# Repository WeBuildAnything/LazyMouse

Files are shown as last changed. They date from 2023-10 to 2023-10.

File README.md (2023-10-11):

# LazyMouse
Based on Arduino library [ESP32 BLE Combo Keyboard & Mouse](https://github.com/blackketter/ESP32-BLE-Combo.git) library by blackketter, which is a fork of T-vK Library.

The IMU sensor uses the [MPU6050 library by Electronic Cats](https://github.com/ElectronicCats/mpu6050.git).

Download and install these libraies before running the code.
# Features
1) Air Mouse with Left and Right Clicks 
2) Vertical and Horizontal Scrolling with Middle Click
3) Volume Control
4) Mute Key
5) Media Control (Play/Pause, Next, Previous)
6) Battery Voltage Sensing and Update every 15 mins

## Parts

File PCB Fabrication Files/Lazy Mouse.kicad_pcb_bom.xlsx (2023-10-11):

designator | quantity | manufacturer | Mfg Part # | value | pack | mount_type
BACK1, L_CLICK1 | 2 | OMRON | D3SH-A0R1 | D3SH-A0R1 | D3SH-_0R1 | smt
C1 | 1 | MURATA | GRM188R72A103KA01J | 10nF | C_0603_1608Metric | smt
C10, C11, C12, C13, C14, C15, C16, C17, C18, C19, C2, C20, C21, C3, C4, C9 | 16 | MURATA | GRM188R72A104KA35J | 0.1uF | C_0603_1608Metric | smt
C5 | 1 | MURATA | GRM1885C2A222JA01D | 2.2nF | C_0603_1608Metric | smt
C6, C8 | 2 | MURATA | GRM188R61A106ME69J | 10uF | C_0603_1608Metric | smt
C7 | 1 | MURATA | GRM188R61C475KE11D | 4.7uF | C_0603_1608Metric | smt
CON1 | 1 |  |  | PinHeader_1x03_P1.00mm_Vertical | PinHeader_1x03_P1.00mm_Vertical | tht
FORWARD1, R_CLICK1 | 2 | OMROM | D3SH-A0L1 | D3SH-A0L1 | D3SH-_0L1 | smt
IC1 | 1 | MICROCHIP | MCP73833 | MCP73833 | SOP50P490X110-10N | smt
IC2 | 1 | TEXAS INSTRUMENTS | LM3671MF | LM3671MF | SOT95P280X145-5N | smt
J1 | 1 | GCT | USB4105-GF-A | USB_C_Receptacle_USB2.0 | USB_C_Receptacle_GCT_USB4105-xx-A_16P_TopMnt_Horizontal | smt
J2 | 1 | MOLEX | 53261-0271 | 53261-0271 | 532610271 | smt
L1 | 1 | TAIYO YUDEN | NRH2412T2R2MNGH | 2.2uH | NRH2412T2R2MNGH | smt
LED1 | 1 | WURTH ELECTRONICS | 150353M153300 | 150353M153300 | 150353M153300 | smt
R1, R15, R2, R3, R4, R5, R6 | 7 | PANASONIC | ERJ-S03J103V | 10k | R_0603_1608Metric | smt
R10, R11, R14, R7, R8 | 5 | PANASONIC | ERJ-P03J122V | 1.2k | R_0603_1608Metric | smt
R12, R13 | 2 | PANASONIC | ERJ-S03J512V | 5.1k | R_0603_1608Metric | smt
R16 | 1 | PANASONIC | ERJ-U03J104V | 100k | R_0603_1608Metric | smt
R9 | 1 | BOURNS | CR0603-FX-54R9ELF | 55 | R_0603_1608Metric | smt
S1 | 1 | E-SWITCH | JS1400BFQ | JS1400BFQ | JS1400BFQ | tht
S2, S3, S4 | 3 | PANASONIC | EVQ-P0N02B | EVQ-P0N02B | EVQP0N02B | smt
S5 | 1 | C&K SWITCHES | PCM12SMTR | PCM12SMTR | PCM12SMTR | tht
S6 | 1 | NIDEC | CSS-1211TB | CSS-1211TB | CSS1211TB | tht
U1 | 1 | TDK | MPU-6050 | MPU-6050 | InvenSense_QFN-24_4x4mm_P0.5mm | smt
U2 | 1 | TT ELECTRONICS | EN10HT1212N5HH3 | EN10HT1212N5HH3 | EN10HT1212N5HH3 | tht
U3 | 1 | ESPRESSIF | ESP32-WROOM-32E-N16 | ESP32-WROOM-32 Wireless Module | ESP32-WROOM-32D | smt

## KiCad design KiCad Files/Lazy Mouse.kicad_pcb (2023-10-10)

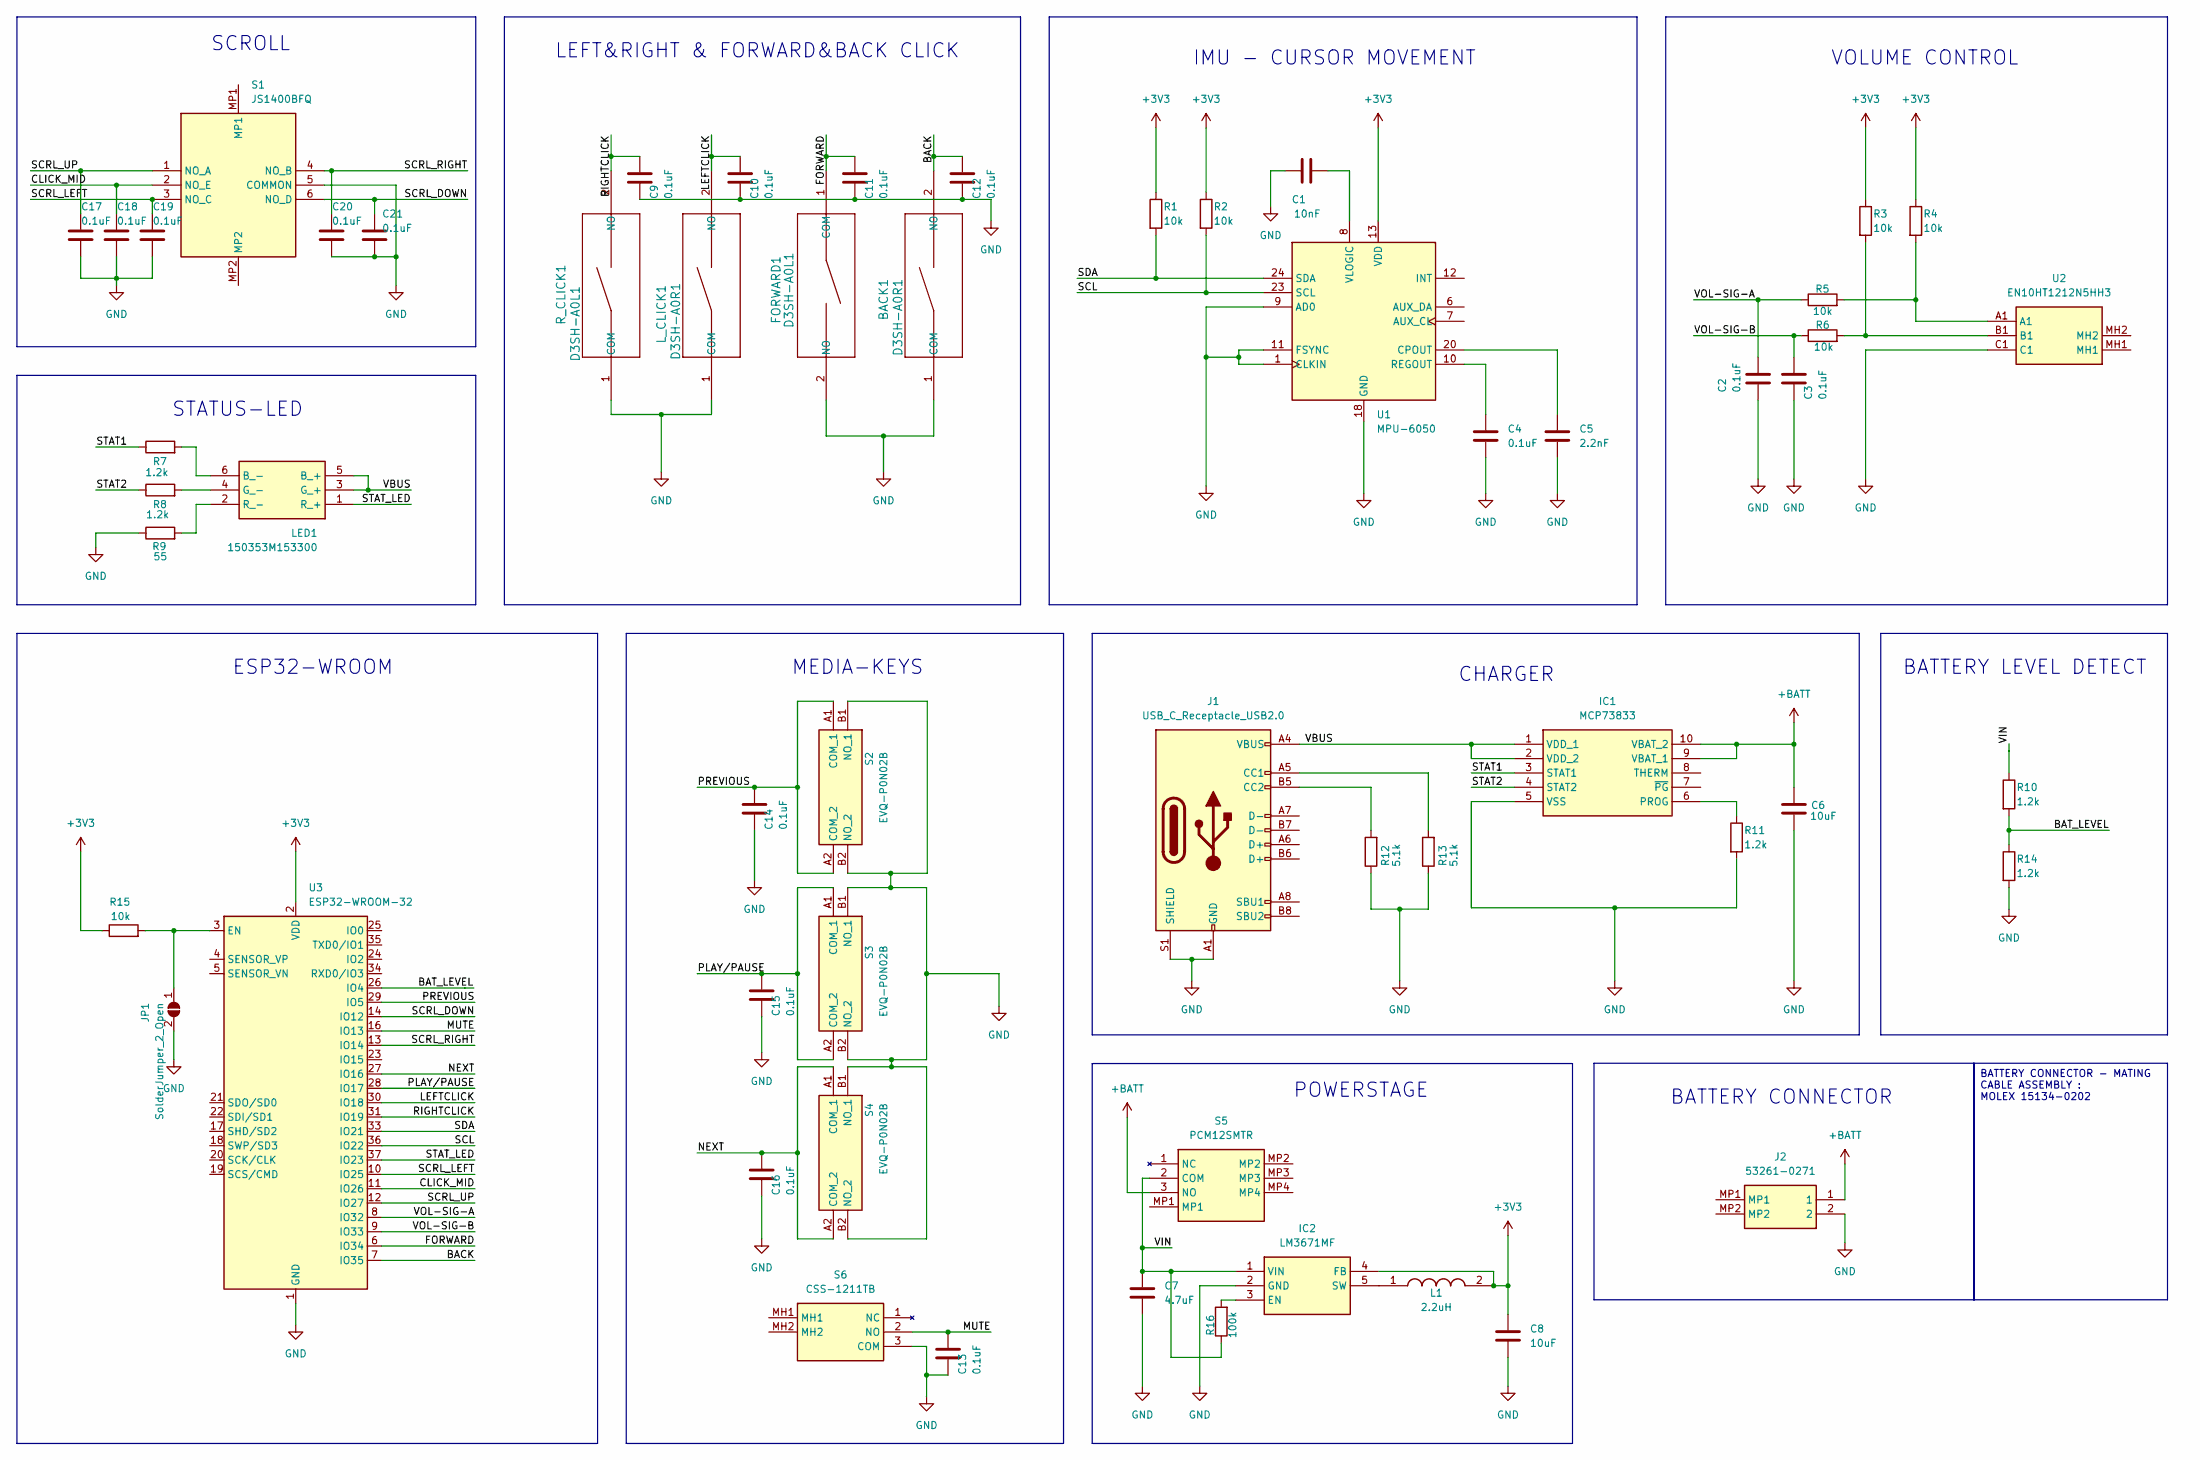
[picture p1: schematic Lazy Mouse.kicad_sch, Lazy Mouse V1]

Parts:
BACK1: D3SH-A0R1; D3SH-_0R1
C1: 10nF; C_0603_1608Metric
C2, C3, C4, C9, C10, C11, C12, C13, C14, C15, C16, C17, C18, C19, C20, C21: 0.1uF; C_0603_1608Metric
C5: 2.2nF; C_0603_1608Metric
C6, C8: 10uF; C_0603_1608Metric
C7: 4.7uF; C_0603_1608Metric
FORWARD1: D3SH-A0L1; D3SH-_0L1
IC1: MCP73833; SOP50P490X110-10N; Mouser Part Number 579-MCP73833-FCI/UN
IC2: LM3671MF; SOT95P280X145-5N; Mouser Part Number 926-LM3671MF125NOPB
J1: USB_C_Receptacle_USB2.0; USB_C_Receptacle_GCT_USB4105-xx-A_16P_TopMnt_Horizontal
J2: 53261-0271; 532610271; Mouser Part Number 538-53261-0271
JP1: SolderJumper_2_Open; SolderJumper-2_P1.3mm_Open_RoundedPad1.0x1.5mm
L1: 2.2uH; NRH2412T2R2MNGH; Mouser Part Number 963-NRH2412T2R2MNGH
LED1: 150353M153300; Mouser Part Number 710-150353M153300
L_CLICK1: D3SH-A0R1; D3SH-_0R1
R1, R2, R3, R4, R5, R6, R15: 10k; R_0603_1608Metric
R7, R8, R10, R11, R14: 1.2k; R_0603_1608Metric
R9: 55; R_0603_1608Metric
R12, R13: 5.1k; R_0603_1608Metric
R16: 100k; R_0603_1608Metric
R_CLICK1: D3SH-A0L1; D3SH-_0L1
S1: JS1400BFQ; Mouser Part Number 612-JS1400BFQ
S2, S3, S4: EVQ-P0N02B; EVQP0N02B; Mouser Part Number 667-EVQ-P0N02B
S5: PCM12SMTR; Mouser Part Number 611-PCM12SMTR
S6: CSS-1211TB; CSS1211TB; Manufacturer_Part_Number CSS-1211TB
U1: MPU-6050; InvenSense_QFN-24_4x4mm_P0.5mm
U2: EN10HT1212N5HH3; Mouser Part Number 858-EN10HT1212N5HH3
U3: ESP32-WROOM-32; ESP32-WROOM-32D

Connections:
+3V3: C8.1, IC2.4 (FB), L1.2, R1.1, R2.1, R3.1, R4.1, R15.1, U1.13 (VDD), U3.2 (VDD)
+BATT: C6.2, IC1.9 (VBAT_1), IC1.10 (VBAT_2), J2.1, S5.3 (NO)
/BACK: BACK1.2 (NO), C12.1, U3.7 (IO35)
/BAT_LEVEL: R10.2, R14.1, U3.26 (IO4)
/CLICK_MID: C18.1, S1.2 (NO_E), U3.11 (IO26)
/FORWARD: C11.1, FORWARD1.1 (COM), U3.6 (IO34)
/LEFTCLICK: C10.1, L_CLICK1.2 (NO), U3.30 (IO18)
/MUTE: C13.1, S6.2 (NO), U3.16 (IO13)
/NEXT: C16.1, S4.A1 (COM_1), S4.A2 (COM_2), U3.27 (IO16)
/PLAY/PAUSE: C15.1, S3.A1 (COM_1), S3.A2 (COM_2), U3.28 (IO17)
/PREVIOUS: C14.1, S2.A1 (COM_1), S2.A2 (COM_2), U3.29 (IO5)
/RIGHTCLICK: C9.1, R_CLICK1.2 (NO), U3.31 (IO19)
/SCL: R2.2, U1.23 (SCL), U3.36 (IO22)
/SCRL_DOWN: C21.1, S1.6 (NO_D), U3.14 (IO12)
/SCRL_LEFT: C19.1, S1.3 (NO_C), U3.10 (IO25)
/SCRL_RIGHT: C20.1, S1.4 (NO_B), U3.13 (IO14)
/SCRL_UP: C17.1, S1.1 (NO_A), U3.12 (IO27)
/SDA: R1.2, U1.24 (SDA), U3.33 (IO21)
/STAT1: IC1.3 (STAT1), R7.1
/STAT2: IC1.4 (STAT2), R8.1
/STAT_LED: LED1.1 (R_+), U3.37 (IO23)
/VBUS: IC1.1 (VDD_1), IC1.2 (VDD_2), J1.A4 (VBUS), J1.A9 (VBUS), J1.B4 (VBUS), J1.B9 (VBUS), LED1.3 (G_+), LED1.5 (B_+)
/VIN: C7.1, IC2.1 (VIN), R10.1, R16.1, S5.2 (COM)
/VOL-SIG-A: C2.1, R5.1, U3.8 (IO32)
/VOL-SIG-B: C3.1, R6.1, U3.9 (IO33)
GND: BACK1.1 (COM), C1.1, C2.2, C3.2, C4.2, C5.2, C6.1, C7.2, C8.2, C9.2, C10.2, C11.2, C12.2, C13.2, C14.2, C15.2, C16.2, C17.2, C18.2, C19.2, C20.2, C21.2, FORWARD1.2 (NO), IC1.5 (VSS), IC2.2 (GND), J1.A1 (GND), J1.A12 (GND), J1.B1 (GND), J1.B12 (GND), J1.S1 (SHIELD), J2.2, JP1.2 (B), L_CLICK1.1 (COM), R9.1, R11.2, R12.1, R13.1, R14.2, R_CLICK1.1 (COM), S1.5 (COMMON), S2.B1 (NO_1), S2.B2 (NO_2), S3.B1 (NO_1), S3.B2 (NO_2), S4.B1 (NO_1), S4.B2 (NO_2), S6.3 (COM), U1.1 (CLKIN), U1.9 (AD0), U1.11 (FSYNC), U1.18 (GND), U2.C1, U3.1 (GND), U3.15 (GND), U3.38 (GND), U3.39 (GND); also elsewhere on the board
unnamed: IC1.6 (PROG), R11.1
unnamed: IC2.3 (EN), R16.2
unnamed: IC2.5 (SW), L1.1
unnamed: J1.A5 (CC1), R13.2
unnamed: J1.B5 (CC2), R12.2
unnamed: JP1.1 (A), R15.2, U3.3 (EN)
unnamed: LED1.6 (B_-), R7.2
unnamed: LED1.4 (G_-), R8.2
unnamed: LED1.2 (R_-), R9.2
unnamed: R3.2, R6.2, U2.B1
unnamed: R4.2, R5.2, U2.A1
unnamed: C5.1, U1.20 (CPOUT)
unnamed: C4.1, U1.10 (REGOUT)
unnamed: C1.2, U1.8 (VLOGIC)

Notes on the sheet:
BATTERY CONNECTOR - MATING CABLE ASSEMBLY : MOLEX 15134-0202
VOLUME CONTROL
BATTERY LEVEL DETECT
MEDIA-KEYS
STATUS-LED
LEFT&RIGHT & FORWARD&BACK CLICK
BATTERY CONNECTOR
IMU - CURSOR MOVEMENT
POWERSTAGE
CHARGER
ESP32-WROOM
SCROLL

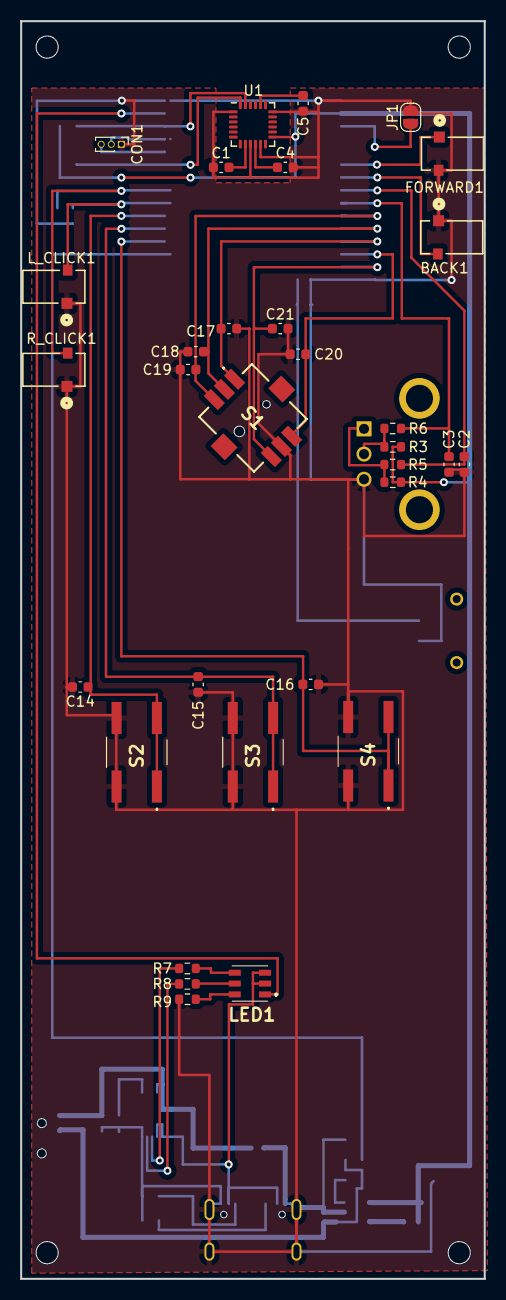
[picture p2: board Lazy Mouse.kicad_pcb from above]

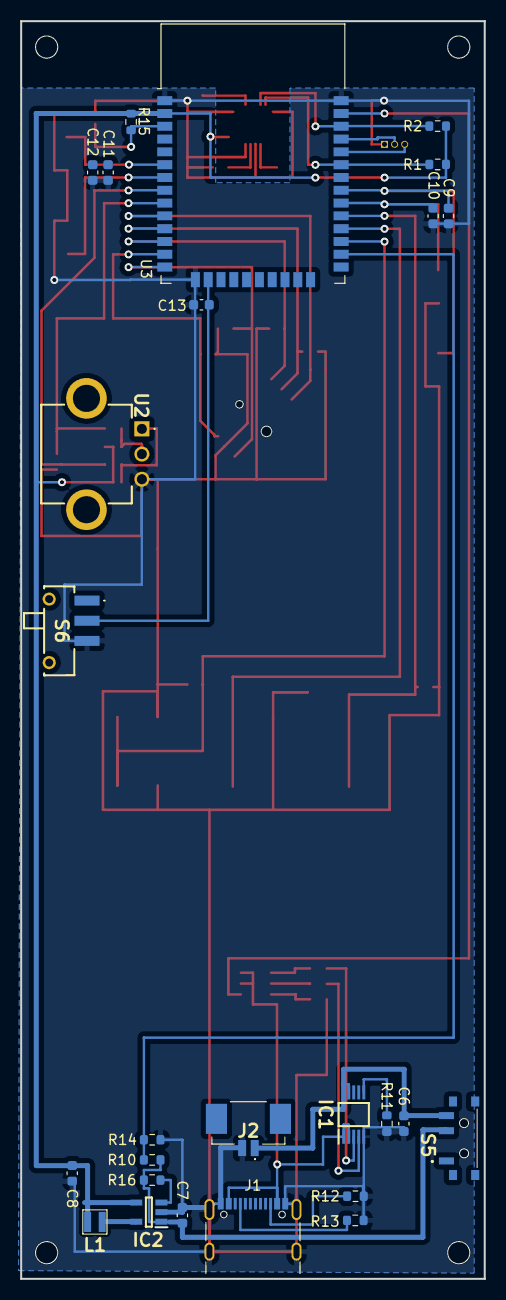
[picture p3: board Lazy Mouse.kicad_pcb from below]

Board: 2 copper layers, 46.0 x 124.8 mm, 62 parts (26 on the bottom side), 40 nets.

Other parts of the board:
CON1: PinHeader_1x03_P1.00mm_Vertical
H1, H2, H3, H4: MountingHole_2.2mm_M2

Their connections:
GND: CON1.1; also elsewhere on the board

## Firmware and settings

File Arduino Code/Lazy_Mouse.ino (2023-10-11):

#include <BleCombo.h>
#include <BleComboKeyboard.h>
#include <Wire.h>
#include <MPU6050.h>

#define BAT_LEVEL 4 //Analog IN
#define STAT_LED 23//Output

//Following pins are input_pullups
#define SCRL_UP 27
#define SCRL_DOWN 12
#define SCRL_RIGHT 14
#define SCRL_LEFT 25

#define CLICK_MID 26

#define LEFTCLICK 18
#define RIGHTCLICK 19

#define FORWARD 34
#define BACK 35

#define PLAY_PAUSE 17
#define NEXT 16
#define PREVIOUS 5

#define VOL_SIG_A 32
#define VOL_SIG_B 33
#define MUTE 13

int pins[] = {5, 12, 13, 14, 16,17,18,19,25,16,27,32,33,34,35};

MPU6050 mpu;
int16_t ax,ay,az,gx,gy,gz; //variable for IMU
int dx, dy; //mapped Variables

unsigned long previousMillis = 0;
const long interval = 900000;
unsigned long currentMillis;
volatile int lastEncoderA = LOW;
volatile int lastEncoderB = LOW;
float bat_volt;
int stat;

void setup()
{
  // put your setup code here, to run once:
  Wire.begin();
  mpu.initialize();
  Mouse.begin();
  Keyboard.begin();
  Serial.begin(115200);
  for(int i=0;i<15;i++)
  {
    pinMode(pins[i],INPUT_PULLUP);
  }
  attachInterrupt(digitalPinToInterrupt(VOL_SIG_A), updateVolume, CHANGE);
  attachInterrupt(digitalPinToInterrupt(VOL_SIG_B), updateVolume, CHANGE);
  bat_volt = (analogRead(BAT_LEVEL)/4095)*3.3;
  stat = map(bat_volt,3,4.2,0,100);
  Keyboard.setBatteryLevel(stat);
}

void loop() {
  currentMillis = millis();
  if(Keyboard.isConnected())
  {
   currentMillis = millis();
    if (currentMillis - previousMillis >= interval)
      {
      previousMillis = currentMillis;
      bat_volt = (analogRead(BAT_LEVEL)/4095)*3.3;
      stat = map(bat_volt,3,4.2,0,100);
      Keyboard.setBatteryLevel(stat);
      }
   //Connected Status
   digitalWrite (STAT_LED,HIGH);
   //Cursor_Move
   mpu.getMotion6(&ax, &ay, &az, &gx, &gy, &gz);
   dx=(gx+260)/150;
   dy=(gy+260)/150;
   Mouse.move(dx,dy);
   //Mouse Funtions
   if (digitalRead(LEFTCLICK) == LOW){
      Mouse.press(MOUSE_LEFT);}
   if (digitalRead(LEFTCLICK) == HIGH) {
      Mouse.release(MOUSE_LEFT);}
   if (digitalRead(RIGHTCLICK) == LOW){
      Mouse.press(MOUSE_RIGHT);}
   if (digitalRead(RIGHTCLICK) == HIGH) {
      Mouse.release(MOUSE_RIGHT);}
   if (digitalRead(CLICK_MID) == LOW){
      Mouse.press(MOUSE_MIDDLE);}
   if (digitalRead(CLICK_MID) == HIGH){
     Mouse.release(MOUSE_MIDDLE);}
   if (digitalRead(FORWARD) == LOW){
     Mouse.click(MOUSE_FORWARD);}
   if (digitalRead(BACK) == LOW){
     Mouse.click(MOUSE_BACK);}
   if (digitalRead(BACK) == LOW){
     Mouse.click(MOUSE_BACK);}
    if (digitalRead(SCRL_UP) == LOW){
     Mouse.move(0,0,1);}
    if (digitalRead(SCRL_DOWN) == LOW){
     Mouse.move(0,0,-1);}
    if (digitalRead(SCRL_RIGHT) == LOW){
     Mouse.move(0,0,0,1);}
    if (digitalRead(SCRL_LEFT) == LOW){
     Mouse.move(0,0,0,-1);} 
    //Media Control
    if (digitalRead(MUTE) == LOW){
     Keyboard.write(KEY_MEDIA_MUTE);}
    if (digitalRead(PLAY_PAUSE) == LOW){
     Keyboard.write(KEY_MEDIA_PLAY_PAUSE);}
    if (digitalRead(NEXT) == LOW){
     Keyboard.write(KEY_MEDIA_NEXT_TRACK);}
    if (digitalRead(PREVIOUS) == LOW){
     Keyboard.write(KEY_MEDIA_PREVIOUS_TRACK);}
  }
  //Blink LED if Bluetooth Disconnected
  else
  {
    digitalWrite(STAT_LED,LOW);
    digitalWrite(STAT_LED,HIGH);
    delay(500);
    digitalWrite(STAT_LED,LOW);
    delay(500);
  }
}

void updateVolume(){
  int encoderA = digitalRead(VOL_SIG_A);
  int encoderB = digitalRead(VOL_SIG_B);
  
  if ((lastEncoderA == LOW && encoderA == HIGH) || (lastEncoderB == LOW && encoderB == HIGH))
    {
    // Clockwise rotation
    Keyboard.write(KEY_MEDIA_VOLUME_UP);
    Serial.println("VolumeUp");
    }   
  else if ((lastEncoderA == HIGH && encoderA == LOW) || (lastEncoderB == HIGH && encoderB == LOW))
    {
    // Counterclockwise rotation
    Keyboard.write(KEY_MEDIA_VOLUME_DOWN);
    Serial.println("Volume Down");
    }
  lastEncoderA = encoderA;
  lastEncoderB = encoderB;
}
